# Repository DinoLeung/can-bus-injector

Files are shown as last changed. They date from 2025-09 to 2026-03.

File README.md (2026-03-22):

# CAN Pulse

## Overview

A simple ESP32-based device that listens to and forwards CAN bus data from the 2022+ Toyota GR86 / Subaru BRZ (ZN8/ZD8).
The goal is to make CAN bus data available in [RaceChrono](https://racechrono.com).
It taps into the ASC unit (the “GazooKazoo”), which reads CAN data to produce fake engine noise. Many owners leave it unplugged anyway, we repurpose the data stream from there.

## Motivation

RaceChrono supports [DIY BLE CAN devices](https://github.com/aollin/racechrono-ble-diy-device), which opens the door to building a fully custom telemetry pipeline. Instead of relying on off-the-shelf hardware, this project aims to create a lightweight, purpose-built device that integrates cleanly with the car and exposes exactly the data needed.

It’s also a practical exercise in understanding the vehicle’s CAN network and building something that is both functional and extensible, rather than a black box.

## Roadmap

### Current Status

The basic firmware is complete and functional:
- CAN frames are read from the vehicle bus.
- Data is cached and filtered.
- Frames are forwarded over BLE using the RaceChrono DIY device protocol.

This means the device is already usable for real-time telemetry in RaceChrono.

### Next Step: High-Rate GPS Integration

The next major milestone is adding high-frequency GPS data support using the [ASL GPS bolt-on](https://wiki.autosportlabs.com/Gps-bolt-on)

Planned capabilities:
- Integrate GPS data alongside CAN telemetry.
- Support higher update rates than typical phone-based GPS.
- Improve lap timing accuracy and track position fidelity.

Longer term, this will allow the device to act as a complete standalone telemetry unit, rather than relying on the phone for positioning data.

## Hardware

### [ASL ESP-CAN-X2](https://wiki.autosportlabs.com/ESP32-CAN-X2)
### [ASL Gps-bolt-on](https://wiki.autosportlabs.com/Gps-bolt-on)

## References

This project is heavily based on reverse engineering work documented by the community, in particular:
- https://github.com/timurrrr/ft86/blob/main/can_bus/gen2.md

That document provides a detailed breakdown of the Gen2 GR86/BRZ CAN bus signals and effectively serves as the foundation for this project. It guided the identification of useful frames, signal meanings, and overall approach to decoding and forwarding data.

Without that work, building a usable and accurate telemetry pipeline would be significantly more time-consuming.

## Oil Pressure Oil Temperature Bolt-on

### Status

Abandon for now or at least deprioritised, due to lack of PCB design skills.

<details>

<summary>details</summary>

### Motivation

The factory setup leaves much to be desired:
- The gauge cluster on BRZ lacks a proper, high-resolution oil temperature gauge.
- Oil pressure data is absent.

This project aims to fill that gap by:
- Forwarding CAN data from the ASC (Active Sound Control) unit to a new CAN output.
- Reading engine oil pressure using a Bosch analog fluid pressure sensor (0 to 10 bar).
- Reading engine oil temperature using a Bosch analog fluid temperature sensor (-40 to 150 °C).
- Injecting that data into the new CAN bus stream so that digital dashboards and logging tools (e.g. RaceChrono) can display it.

Accurate oil pressure monitoring is critical in performance and track environments — especially given the FA24 platform’s known vulnerability to oil starvation during high-G right-hand turns.

### Features

- Dual-CAN forwarding: Reads from CAN1 (TWAI), writes to CAN2 (MCP2515).
- Sensor integration: Adds real-time oil pressure and temperature data (40Hz sampling rate, 20Hz update rate).
- Plug-and-play install: Designed to interface cleanly with the ASC connector and ESP32.

### Hardware

#### [Custom ASL ESP32-CAN-X2 Bolt-on](./bolt-on-bosch-pst-f-1/)
#### [Bosch Pressure Sensor Combined PST-F 1](https://www.bosch-motorsport.com/content/downloads/Raceparts/en-GB/54249355.html)

</details>

## License

- **Firmware** (ESP32 code): [GPLv3](./LICENSE)
- **Hardware design** (schematics, PCB layout): [CERN-OHL-S v2](./bolt-on-bosch-pst-f-1/LICENSE)

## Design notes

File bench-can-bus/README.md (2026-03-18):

# Bench top can bus

This is to save me from getting actual can signal from the car while writing code. 

It's purely vibe coded, making [FakeSubaruBRZ.ino](https://github.com/timurrrr/arduino-CAN/blob/master/examples/FakeSubaruBRZ/FakeSubaruBRZ.ino) compatible with ESP32-CAN-X2, producing CAN data on CAN 1.

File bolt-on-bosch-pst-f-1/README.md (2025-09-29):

# PST-F1 Bolt-On Daughter Board for ESP32-CAN-X2

A small daughter-board that lets you easily attach a Bosch PST-F1 combined pressure + temperature sensor to the AutosportLabs ESP32-CAN-X2.

## Overview

This daughter-board provides ESP32-CAN-X2 an interface for the Bosch PST-F1 combined pressure and temperature sensor (0–10 bar pressure + NTC temperature). It uses a 4-pin JST connector for sensor inputs. The board also passes through CAN2 signals from the ESP32-CAN-X2.

## Features

- **PST-F1 support**: 4-pin input (5 V, PRESS_SIG, TEMP_SIG, GND)
- **Voltage scaling & protection** on both sensor outputs
- **0.1 µF decoupling** on analog rails
- **Pass-through** of CAN2 channel

## Hardware Requirements

- [AutosportLabs ESP32-CAN-X2](https://wiki.autosportlabs.com/ESP32-CAN-X2) board
- [Bosch PST-F1 combined pressure-temperature sensor](https://www.bosch-motorsport.com/content/downloads/Raceparts/en-GB/54249355.html)

## Pinout & Connections

| PST-F1 Pin | Signal | Daughter-Board Net | ESP32-CAN-X2 Pin |
|:---:|:---|:---|:---:|
| 1 | +5 V Supply  | 5V | SV1-pin 15 (5 V) |
| 2 | PRESS_SIG | PRESS_ADC | SV2-pin 13 (GPIO)|
| 3 | TEMP_SIG | TEMP_ADC | SV2-pin 12 (GPIO)|
| 4 | GND | GND | SV1-pin 16 (GND) |

## Analog Signal Scaling/Divider

### Pressure (0–10 bar → 0.32–2.88 V ADC)

- At 0.5 V (@ 0 bar / 0 PSI) -> ADC ≈ 0.32 V
- At 4.5 V (@ 10 bar / 145 PSI) -> ADC ≈ 2.88 V

``` mermaid
flowchart LR
  PSTF1_P["PST-F1 Pressure Out<br/>0.5 V @ 0 bar – 4.5 V @ 10 bar"]
  PRESS_ADC["PRESS_ADC Node"]
  R_SER_PRESS["R_SER_PRESS<br/>220 Ω"]
  R_PRESS_TOP["R_PRESS_TOP<br/>5.6 kΩ"]
  R_PRESS_BOT["R_PRESS_BOT<br/>10 kΩ"]
  D1["D1<br/>BAT54C"]
  D2["D2<br/>BAT54A"]
  C1["C1 Filter Cap<br/>0.1 µF"]
  GND["GND"]
  VCC["3.3 V"]
  GPIO["GPIO 35"]

  PSTF1_P --- R_SER_PRESS --- R_PRESS_TOP --- PRESS_ADC
  VCC ---|cathode| D1
  D1 ---|anode| PRESS_ADC
  GND ---|anode| D2
  D2 ---|cathode| PRESS_ADC
  PRESS_ADC --- R_PRESS_BOT --- GND
  PRESS_ADC --- C1 --- GND
  PRESS_ADC --- GPIO
```

### Temperature (NTC 58.1 Ω-44.864 kΩ → 0.01–2.9 V ADC)

- At cold (44 kΩ) → ADC ≈ 2.9 V
- At hot (58 Ω) → ADC ≈ 0.01 V

``` mermaid
flowchart LR
  PSTF1_P["PST-F1 Temperature Out<br/>44 kΩ @ –40 °C - 58 Ω @ +150 °C"]
  R_SER_TEMP["R_SER_TEMP<br/>220 Ω"]
  R_TEMP_TOP["R_TEMP_TOP<br/>6.8 kΩ"]
  TEMP_ADC["TEMP_ADC Node"]
  D1["D1<br/>BAT54C"]
  D2["D2<br/>BAT54A"]
  C2["C2 Filter Cap<br/>0.1 µF"]
  GND["GND"]
  VCC["3.3 V"]
  GPIO["GPIO 36"]

  PSTF1_P --- R_SER_TEMP --- TEMP_ADC
  TEMP_ADC --- C2 --- GND
  TEMP_ADC --- R_TEMP_TOP --- VCC
  VCC ---|cathode| D1  ---|anode| TEMP_ADC
  GND ---|anode| D2
  D2 ---|cathode| TEMP_ADC
  TEMP_ADC --- GPIO
```

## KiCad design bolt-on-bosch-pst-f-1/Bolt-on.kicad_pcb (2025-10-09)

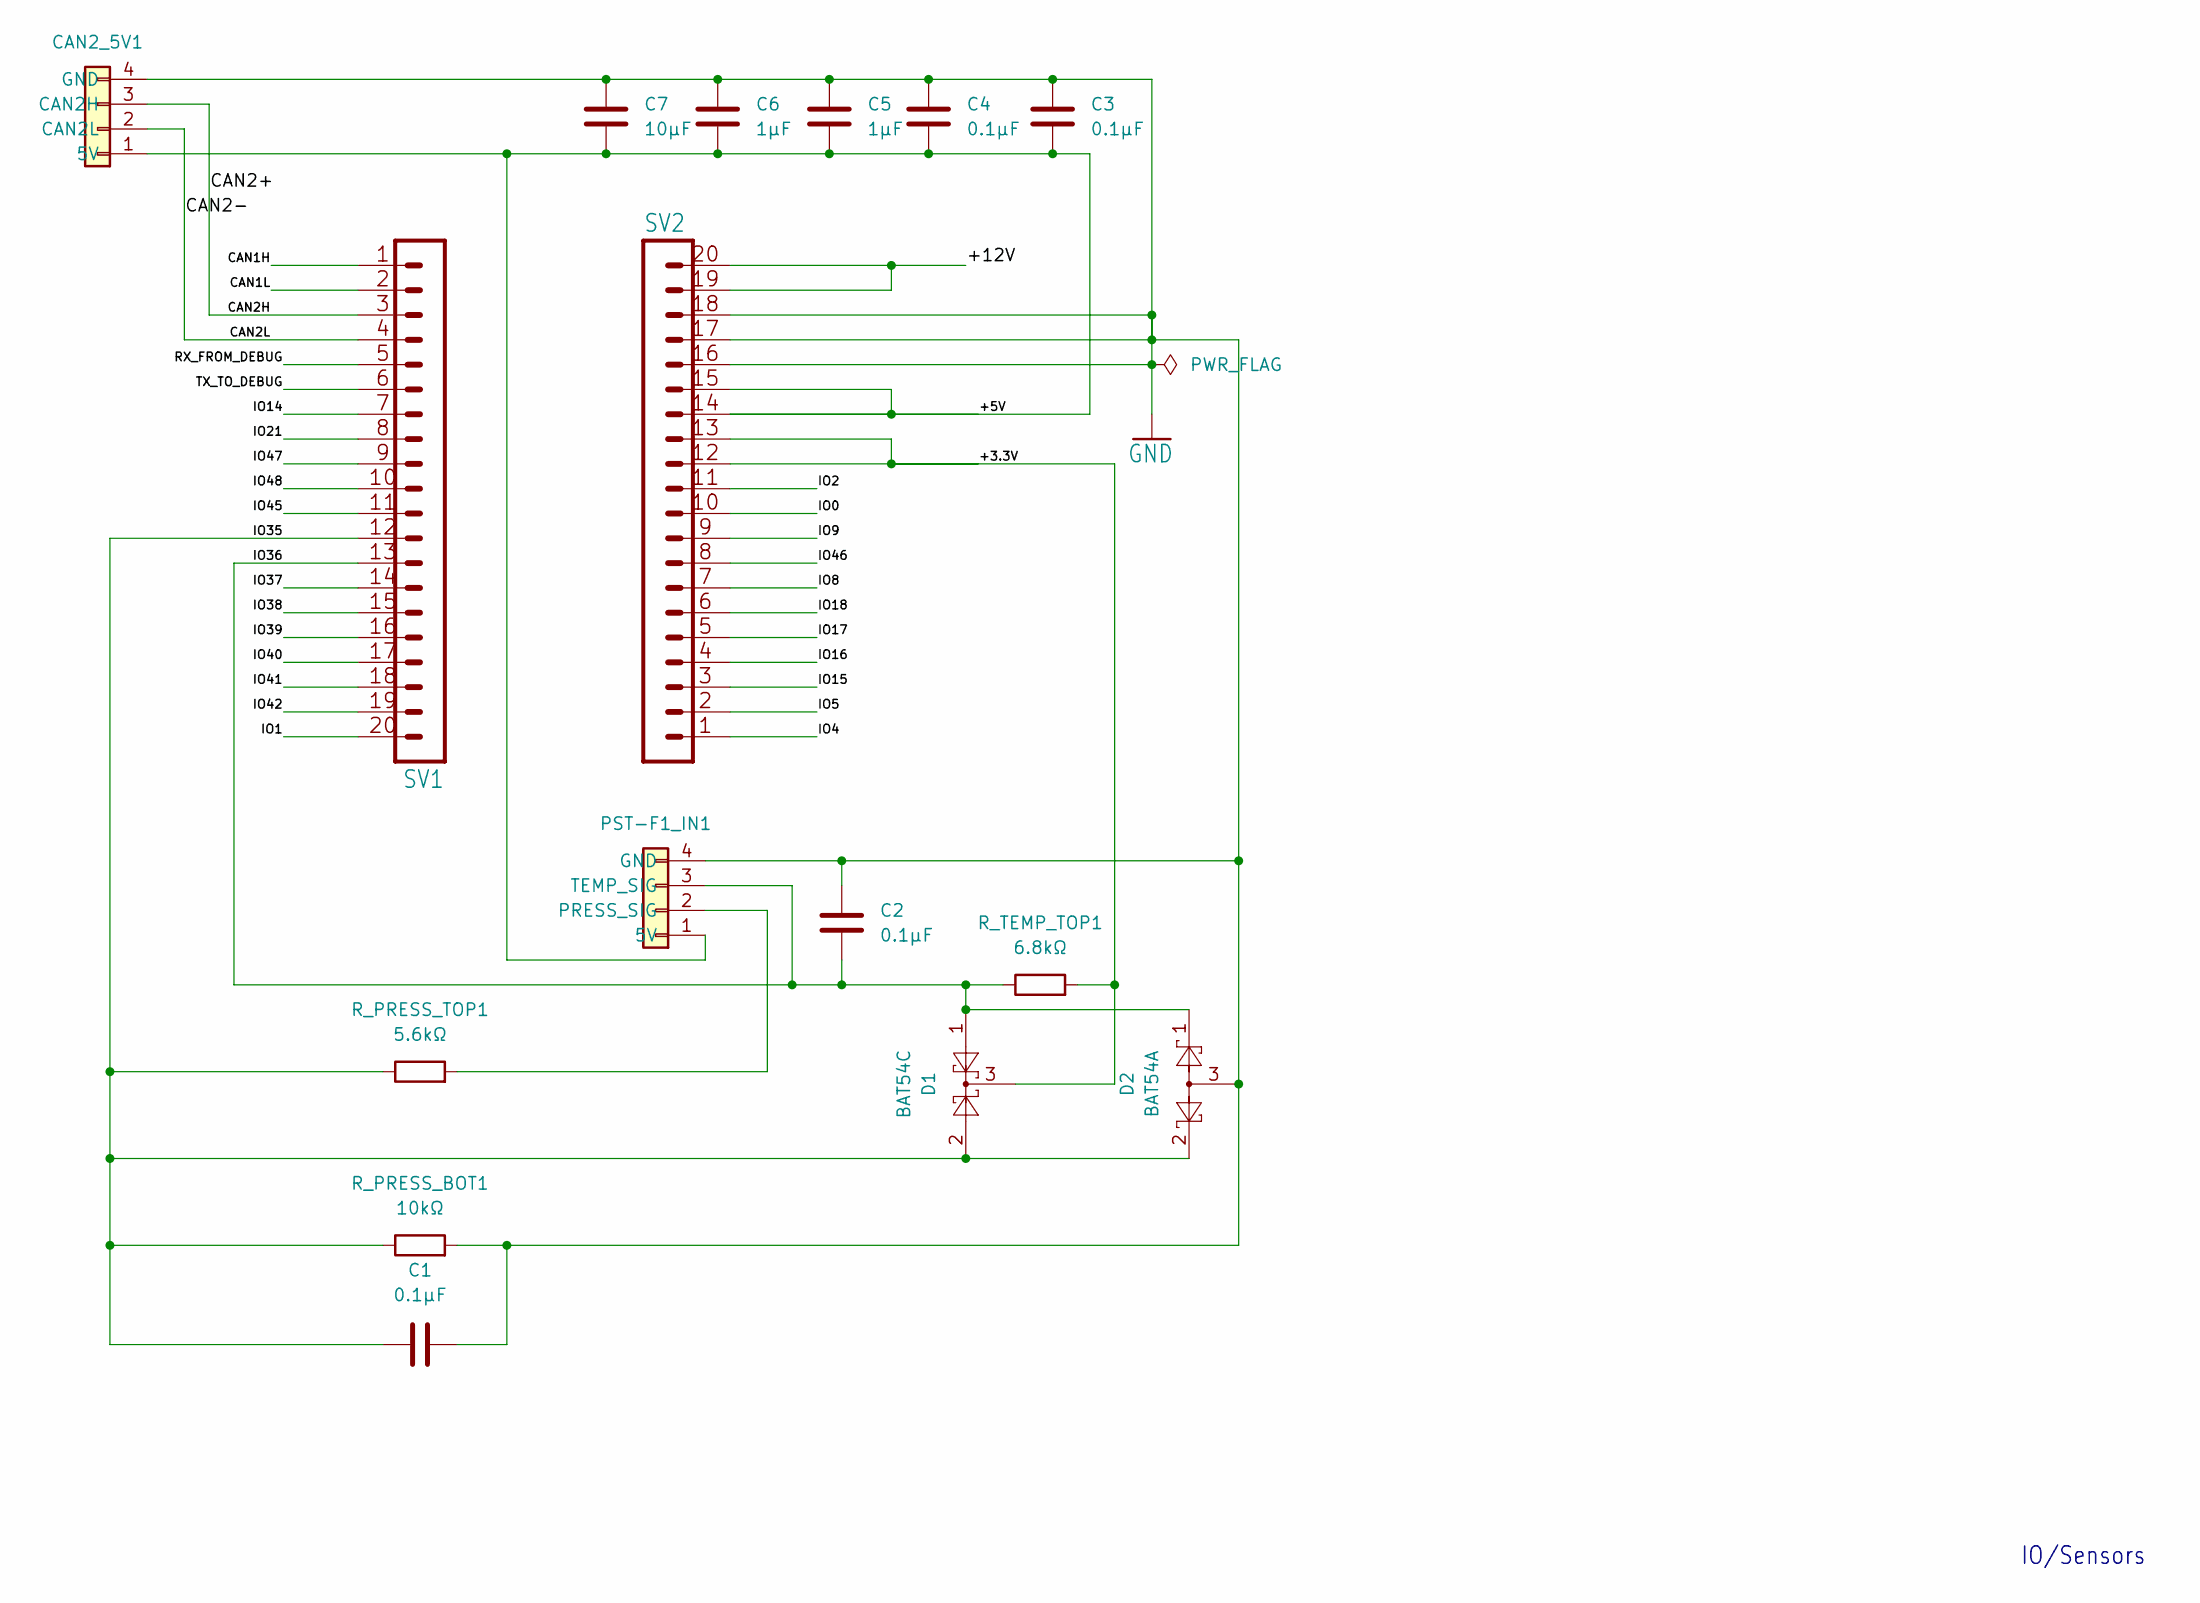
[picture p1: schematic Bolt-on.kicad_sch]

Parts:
C1, C2, C3, C4:  0.1µF; C_0805_2012Metric_Pad1.18x1.45mm_HandSolder
C5, C6: 1µF; C_0805_2012Metric_Pad1.18x1.45mm_HandSolder
C7: 10µF; C_1206_3216Metric_Pad1.33x1.80mm_HandSolder
CAN2_5V1: Conn_01x04; JST_PH_S4B-PH-SM4-TB_1x04-1MP_P2.00mm_Horizontal
D1: BAT54C; SOT-23_Handsoldering
D2: BAT54A; TSOT-23_HandSoldering
PST-F1_IN1: Conn_01x04; JST_PH_S4B-PH-SM4-TB_1x04-1MP_P2.00mm_Horizontal
R_PRESS_BOT1:  10kΩ; R_0805_2012Metric_Pad1.20x1.40mm_HandSolder
R_PRESS_TOP1:  5.6kΩ; R_0805_2012Metric_Pad1.20x1.40mm_HandSolder
R_TEMP_TOP1:  6.8kΩ; R_0805_2012Metric_Pad1.20x1.40mm_HandSolder
SV1, SV2: MA20-1L_162

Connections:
/+3.3V: D1.3, R_TEMP_TOP1.2, SV2.12, SV2.13
/+5V: C3.2, C4.2, C5.2, C6.2, C7.2, CAN2_5V1.1 (5V), PST-F1_IN1.1 (5V), SV2.14, SV2.15
/+12V: SV2.19, SV2.20
/CAN1H: SV1.1
/CAN1L: SV1.2
/CAN2+: CAN2_5V1.3 (CAN2H), SV1.3
/CAN2-: CAN2_5V1.2 (CAN2L), SV1.4
/IO0: SV2.10
/IO1: SV1.20
/IO2: SV2.11
/IO4: SV2.1
/IO5: SV2.2
/IO8: SV2.7
/IO9: SV2.9
/IO14: SV1.7
/IO15: SV2.3
/IO16: SV2.4
/IO17: SV2.5
/IO18: SV2.6
/IO21: SV1.8
/IO35: C1.2, D1.2, D2.2, R_PRESS_BOT1.1, R_PRESS_TOP1.1, SV1.12
/IO36: C2.2, D1.1, D2.1, PST-F1_IN1.3 (TEMP_SIG), R_TEMP_TOP1.1, SV1.13
/IO37: SV1.14
/IO38: SV1.15
/IO39: SV1.16
/IO40: SV1.17
/IO41: SV1.18
/IO42: SV1.19
/IO45: SV1.11
/IO46: SV2.8
/IO47: SV1.9
/IO48: SV1.10
/RX_FROM_DEBUG: SV1.5
/TX_TO_DEBUG: SV1.6
GND: C1.1, C2.1, C3.1, C4.1, C5.1, C6.1, C7.1, CAN2_5V1.4 (GND), D2.3, PST-F1_IN1.4 (GND), R_PRESS_BOT1.2, SV2.16, SV2.17, SV2.18
unnamed: PST-F1_IN1.2 (PRESS_SIG), R_PRESS_TOP1.2

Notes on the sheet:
IO/Sensors

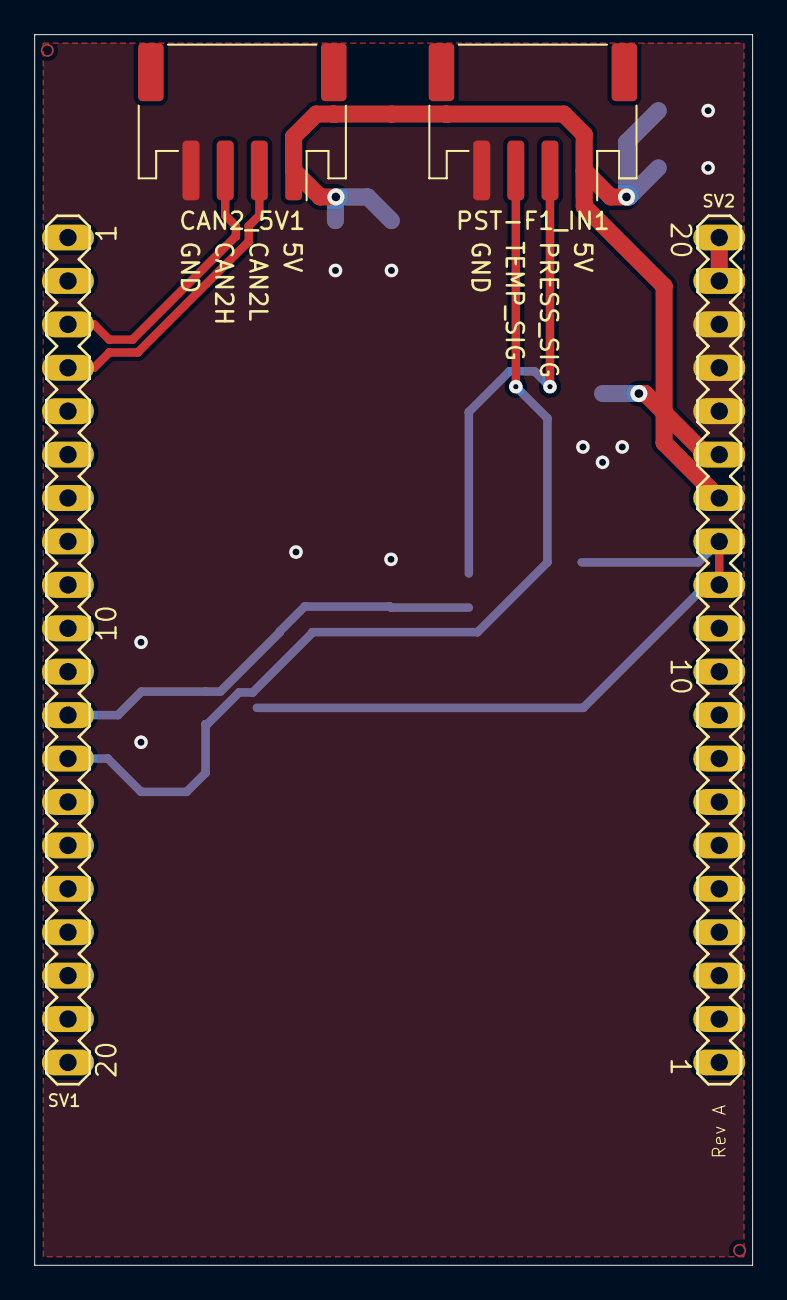
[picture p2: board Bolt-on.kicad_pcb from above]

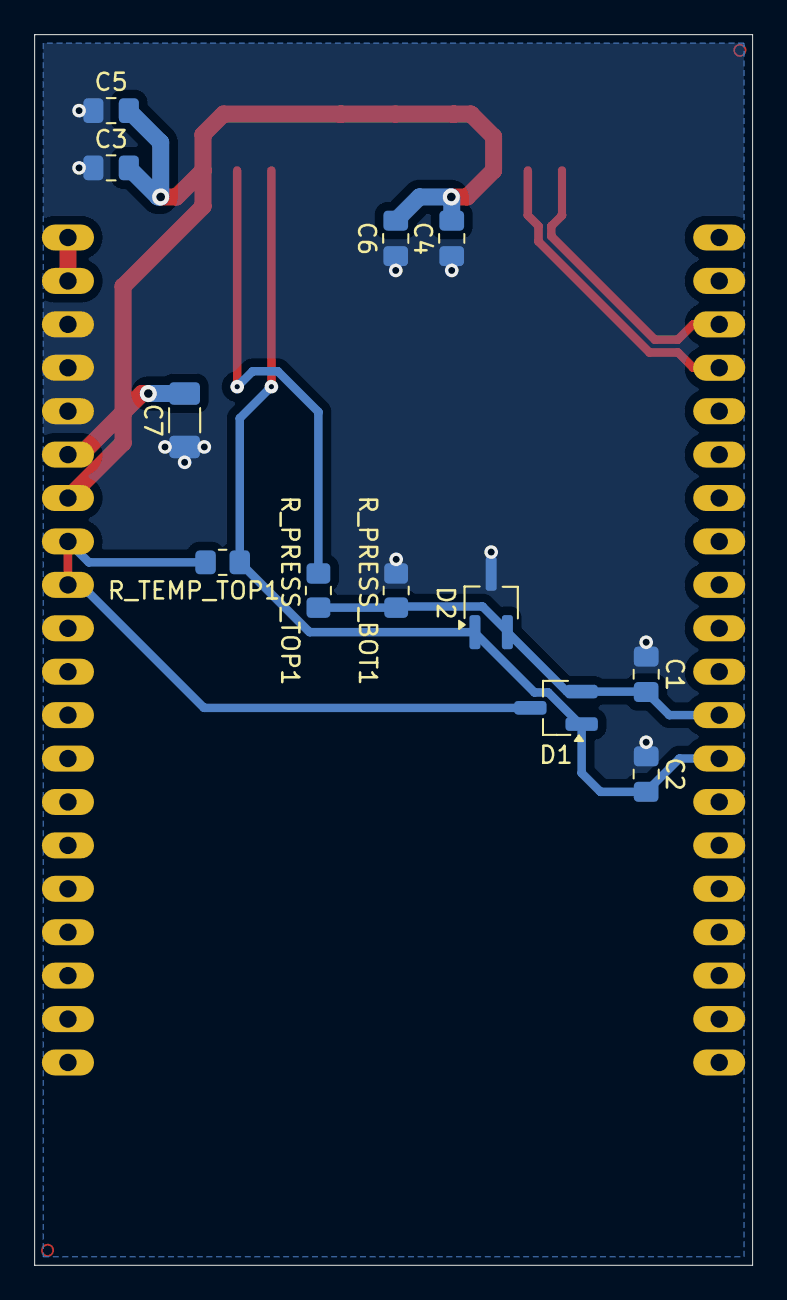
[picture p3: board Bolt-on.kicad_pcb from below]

Board: 2 copper layers, 42.0 x 72.0 mm, 16 parts (12 on the bottom side), 9 nets.

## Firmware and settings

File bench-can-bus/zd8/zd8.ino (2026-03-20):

#include <Arduino.h>
#include "driver/twai.h"

// BRZ bus speed from the original example
static constexpr uint32_t CAN_BITRATE = 500000;

// -------------------------------------------------------------------------------------------------
// Frame scheduler
// -------------------------------------------------------------------------------------------------

struct ScheduledPid {
  uint16_t pid;
  uint16_t rate_hz;
  uint32_t last_sent_us;
};

// Keep the same spirit as the original example:
// - 0x18, 0x140, 0x141, 0x142 at 100 Hz
// - several others at 50 / 20 / 10 / 16.7 Hz
ScheduledPid scheduledPids[] = {
  
  // somewhat real can data
  {0x040, 100, 0},
  {0x138,  50, 0},
  {0x139,  50, 0},
  {0x13B,  50, 0},
  {0x146,  50, 0},
  {0x241,  50, 0},
  {0x345,  50, 0},
  
  // placeholders
  {0x018, 100, 0},
  {0x390,  50, 0},
  {0x141, 100, 0},
  {0x142, 100, 0},
  {0x144,  50, 0},
  {0x152,  50, 0},
  {0x156,  50, 0},
  {0x280,  50, 0},
  {0x282,  17, 0},
  {0x284,  10, 0},

};

// -------------------------------------------------------------------------------------------------
// Helpers
// -------------------------------------------------------------------------------------------------

static inline uint16_t hzToPeriodUs(uint16_t hz) {
  return 1000000UL / hz;
}

bool sendFrame(uint16_t id, const uint8_t *payload, uint8_t len) {
  twai_message_t msg = {};
  msg.identifier = id;
  msg.extd = 0;
  msg.rtr = 0;
  msg.data_length_code = len;
  memcpy(msg.data, payload, len);

  esp_err_t err = twai_transmit(&msg, pdMS_TO_TICKS(50));
  if (err != ESP_OK) {
    Serial.printf("TX failed id=0x%03X err=%d\n", id, err);
    return false;
  }
  return true;
}

// -------------------------------------------------------------------------------------------------
// Fake BRZ payload generation
// -------------------------------------------------------------------------------------------------

void generatePayload(uint16_t pid, uint8_t *payload) {
  memset(payload, 0, 8);

  switch (pid) {
    case 0x018: {
      // Placeholder heartbeat frame.
      payload[0] = 0x00;
      payload[1] = 0x00;
      payload[2] = 0x00;
      payload[3] = 0x00;
      payload[4] = 0x00;
      payload[5] = 0x00;
      payload[6] = 0x00;
      payload[7] = 0x00;
      break;
    }

    case 0x040: {
      // engine speed / accelerator pos
      payload[0] = 0x00;
      payload[1] = 0x00;
      payload[2] = 0xCF;
      payload[3] = 0x82;
      payload[4] = 0x99;
      payload[5] = 0x00;
      payload[6] = 0x00;
      payload[7] = 0x00;
      break;
    }

    case 0x138: {
      // Steering / yaw
      payload[0] = 0x00;
      payload[1] = 0x00;
      payload[2] = 0xC1;
      payload[3] = 0xFF;
      payload[4] = 0xFA;
      payload[5] = 0x3F;
      payload[6] = 0x00;
      payload[7] = 0x00;
      break;
    }

    case 0x139: {
      // Speed / break pressure
      payload[0] = 0x00;
      payload[1] = 0x00;
      payload[2] = 0xFC;
      payload[3] = 0xE0;
      payload[4] = 0x00;
      payload[5] = 0x01;
      payload[6] = 0x00;
      payload[7] = 0x00;
      break;
    }

    case 0x13B: {
      // acceleration
      payload[0] = 0x00;
      payload[1] = 0x00;
      payload[2] = 0x00;
      payload[3] = 0x00;
      payload[4] = 0x00;
      payload[5] = 0x0;
      payload[6] = 0xFE;
      payload[7] = 0xFD;
      break;
    }

    case 0x146: {
      // acceleration
      payload[0] = 0x00;
      payload[1] = 0x00;
      payload[2] = 0x00;
      payload[3] = 0x00;
      payload[4] = 0x89;
      payload[5] = 0x00;
      payload[6] = 0x00;
      payload[7] = 0x00;
      break;
    }

    case 0x241: {
      // acceleration
      payload[0] = 0x00;
      payload[1] = 0x00;
      payload[2] = 0x00;
      payload[3] = 0x00;
      payload[4] = 0x30;
      payload[5] = 0x00;
      payload[6] = 0x00;
      payload[7] = 0x00;
      break;
    }

    case 0x345: {
      // acceleration
      payload[0] = 0x00;
      payload[1] = 0x00;
      payload[2] = 0x00;
      payload[3] = 0x84;
      payload[4] = 0x82;
      payload[5] = 0x12;
      payload[6] = 0x00;
      payload[7] = 0x00;
      break;
    }
    
    case 0x390: {
      // acceleration
      payload[0] = 0x00;
      payload[1] = 0x00;
      payload[2] = 0x00;
      payload[3] = 0x00;
      payload[4] = 0x90;
      payload[5] = 0x00;
      payload[6] = 0x00;
      payload[7] = 0x00;
      break;
    }

    case 0x0D2: {
      // Placeholder
      payload[0] = 0x11;
      payload[1] = 0x22;
      payload[2] = 0x33;
      payload[3] = 0x44;
      break;
    }

    case 0x0D3: {
      // Placeholder
      payload[0] = 0x55;
      payload[1] = 0x66;
      payload[2] = 0x77;
      payload[3] = 0x88;
      break;
    }

    case 0x141: {
      // Placeholder
      payload[0] = 0x01;
      payload[1] = 0x02;
      payload[2] = 0x03;
      payload[3] = 0x04;
      break;
    }

    case 0x142: {
      // Placeholder
      payload[0] = 0x10;
      payload[1] = 0x20;
      payload[2] = 0x30;
      payload[3] = 0x40;
      break;
    }

    case 0x144: {
      // Placeholder
      payload[0] = 0xAA;
      payload[1] = 0xBB;
      payload[2] = 0xCC;
      payload[3] = 0xDD;
      break;
    }

    case 0x152: {
      // Placeholder
      payload[0] = 0x12;
      payload[1] = 0x34;
      payload[2] = 0x56;
      payload[3] = 0x78;
      break;
    }

    case 0x156: {
      // Placeholder
      payload[0] = 0x9A;
      payload[1] = 0xBC;
      payload[2] = 0xDE;
      payload[3] = 0xF0;
      break;
    }

    case 0x280: {
      // Placeholder
      payload[0] = 0x01;
      break;
    }

    case 0x282: {
      // Placeholder
      payload[0] = 0x02;
      break;
    }

    case 0x284: {
      // Placeholder
      payload[0] = 0x03;
      break;
    }

    default:
      break;
  }
}

// -------------------------------------------------------------------------------------------------
// Setup / loop
// -------------------------------------------------------------------------------------------------

void setup() {
  Serial.begin(115200);
  delay(300);

  Serial.println("Initializing CAN1 (TWAI) on ESP32-CAN-X2...");

  twai_general_config_t g_config =
    TWAI_GENERAL_CONFIG_DEFAULT((gpio_num_t)CAN1_TX, (gpio_num_t)CAN1_RX, TWAI_MODE_NO_ACK);
  twai_timing_config_t t_config = TWAI_TIMING_CONFIG_500KBITS();
  twai_filter_config_t f_config = TWAI_FILTER_CONFIG_ACCEPT_ALL();

  esp_err_t err = twai_driver_install(&g_config, &t_config, &f_config);
  if (err != ESP_OK) {
    Serial.printf("twai_driver_install failed: %d\n", err);
    while (true) delay(1000);
  }

  err = twai_start();
  if (err != ESP_OK) {
    Serial.printf("twai_start failed: %d\n", err);
    while (true) delay(1000);
  }

  Serial.println("CAN1 started at 500 kbit/s");
}

void loop() {
  uint32_t nowUs = micros();

  for (size_t i = 0; i < sizeof(scheduledPids) / sizeof(scheduledPids[0]); i++) {
    ScheduledPid &entry = scheduledPids[i];
    const uint32_t periodUs = hzToPeriodUs(entry.rate_hz);

    if ((uint32_t)(nowUs - entry.last_sent_us) >= periodUs) {
      uint8_t payload[8];
      generatePayload(entry.pid, payload);

      if (sendFrame(entry.pid, payload, 8)) {
        entry.last_sent_us = nowUs;
      } else {
        // Don't spam this too hard on a busy bus
        Serial.printf("TX failed for 0x%03X\n", entry.pid);
      }
    }
  }

  // Keep loop tight but not stupidly busy
  delayMicroseconds(200);
}

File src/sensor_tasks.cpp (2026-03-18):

#include "sensor_tasks.h"
#include <Arduino.h>
#include <cmath>
#include "sensor_readings.h"
#include "sensor_math.h"
#include "can_bus.h"

// PST-F1 signal pins
#define PRESSURE_PIN GPIO_NUM_35
#define TEMPERATURE_PIN GPIO_NUM_36

// Custom CAN ID
#define CAN_ID 0x7e0

// 40Hz
constexpr TickType_t sensorSampleInterval = pdMS_TO_TICKS(25);
// 20Hz
constexpr TickType_t sensorCanMsgInterval = pdMS_TO_TICKS(50);

void pressureSamplingTask(void*);
void temperatureSamplingTask(void*);
static void sensorCanWriterTask(void*);

void startSensorTasks() {
	// Configure ADC resolution and attenuation for analog sensors
	analogReadResolution(12);
	analogSetPinAttenuation(PRESSURE_PIN, ADC_11db);
	analogSetPinAttenuation(TEMPERATURE_PIN, ADC_11db);

	xTaskCreate(pressureSamplingTask, "Oil_Pres", 2048, NULL, 1, NULL);
	xTaskCreate(temperatureSamplingTask, "Oil_Temp", 2048, NULL, 1, NULL);
	xTaskCreate(sensorCanWriterTask, "Sensor_CAN_Writer", 2048, NULL, 1, NULL);
}

/**
 * @brief FreeRTOS task that samples and processes oil pressure sensor readings.
 *
 * This task runs at 40 Hz. It reads the analog voltage from the oil pressure sensor,
 * converts it to voltage using adcToVoltage(), then computes pressure in psi via computePressurePsi().
 * The computed value is scaled to 0.1 psi resolution and stored in g_oilPressurePsi10.
 * If the ADC voltage is invalid, g_oilPressurePsi10 is set to INT16_MAX.
 *
 * @param pvParameters Unused.
 */
void pressureSamplingTask(void* pvParameters) {
	(void)pvParameters;
	TickType_t lastWake = xTaskGetTickCount();
	while (true) {
		int raw = analogRead(PRESSURE_PIN);
		float vAdc = adcToVoltage(raw);
		float pressurePsi = computePressurePsi(vAdc);

		if (isnan(pressurePsi)) {
			g_oilPressurePsi10 = INT16_MAX;
		} else {
			g_oilPressurePsi10 = static_cast<uint16_t>(pressurePsi * 10.0f);
		}

		vTaskDelayUntil(&lastWake, sensorSampleInterval);
	}
}

/**
 * @brief FreeRTOS task that samples and processes oil temperature sensor readings.
 *
 * This task runs at 40 Hz. It reads the analog voltage from the NTC temperature sensor,
 * converts it to voltage using adcToVoltage(), then computes temperature in Celsius
 * via computeTemperatureC(). The computed value is scaled to 0.1 °C resolution and stored in g_oilTempC10.
 * If the ADC voltage is invalid, g_oilTempC10 is set to INT16_MAX.
 *
 * @param pvParameters Unused.
 */
void temperatureSamplingTask(void* pvParameters) {
	(void)pvParameters;
	TickType_t lastWake = xTaskGetTickCount();
	while (true) {
		int raw = analogRead(TEMPERATURE_PIN);
		float vAdc = adcToVoltage(raw);
		float tempC = computeTemperatureC(vAdc);

		if (isnan(tempC)) {
			g_oilTempC10 = INT16_MAX;
		} else {
			g_oilTempC10 = static_cast<int16_t>(tempC * 10.0f);
		}

		vTaskDelayUntil(&lastWake, sensorSampleInterval);
	}
}

/**
 * @brief FreeRTOS task that periodically sends combined sensor values to CAN2.
 *
 * This task constructs a 4-byte CAN frame every 50 ms (20 Hz) that includes:
 * - Bytes 0–1: Oil pressure in deci-psi (uint16_t)
 * - Bytes 2–3: Oil temperature in deci-degrees Celsius (int16_t, two's complement)
 *
 * The values are read from shared volatile variables `g_oilPressurePsi10` and `g_oilTempC10`,
 * and sent as a standard 11-bit CAN frame using the identifier defined by `CAN_ID`.
 *
 * @param pvParameters Unused parameter for FreeRTOS compatibility.
 */
void sensorCanWriterTask(void* pvParameters) {
	(void)pvParameters;
	TickType_t lastWake = xTaskGetTickCount();
	while (true) {
		twai_message_t msg{};
		// Pack signed temperature (deci-°C) as two's‑complement uint16_t
		uint16_t rawTemp = static_cast<uint16_t>(g_oilTempC10);
		msg.identifier = CAN_ID;
		msg.extd = 0;
		msg.data_length_code = 4;
		msg.data[0] = uint8_t(g_oilPressurePsi10 >> 8);
		msg.data[1] = uint8_t(g_oilPressurePsi10 & 0xFF);
		msg.data[2] = uint8_t(rawTemp >> 8);
		msg.data[3] = uint8_t(rawTemp & 0xFF);
		writeCan2(msg);
		vTaskDelayUntil(&lastWake, sensorCanMsgInterval);
	}
}

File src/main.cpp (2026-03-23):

#include <Arduino.h>
#include "can_bus.h"
#include "can_frame_cache.h"
#include "gps.h"
#include "rc_ble.h"
#include "sensor_tasks.h"
#include "can_tasks.h"
#include "gps_tasks.h"
#include "rc_ble_tasks.h"

void setup() {
	initCanFrameCache();

	initCanBus();
	// initGps();
	initRaceChronoBle();
	
	startCanTasks();
	// startGpsTasks();
	// startSensorTasks();
	startRaceChronoTasks();
}

void loop() { /* DO NOTHING */ }

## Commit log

2025-07-18 designing circuit board for bosch sensor
    [Bolt-On Template.brd, Bolt-On Template.sch]
2025-07-25 designed circuit board for bosch sensor
    [Bolt-On Template.brd, Bolt-On Template.sch]
2025-07-25 added labels to circuit board
    [Bolt-On Template.brd]
2025-07-26 added readme for daughter board design
    [Bolt-On Template.brd, Bolt-On Template.sch]
2025-07-26 cleanup board design
    [Bolt-On Template.brd, Bolt-On Template.sch]
2025-07-27 implement basic can bus forwarder logic
2025-07-27 fix can1ReadTask param typo
    [main.cpp]
2025-07-27 implemented sensor sample logic, and custom can writer logic
2025-07-28 update temperature to signed int, update data sample tasks to 40hz
2025-07-29 add labels to jst pins
    [Bolt-On Template.brd, Bolt-On Template.sch]
2025-07-30 implement Steinhart–Hart equation for temps sensor
2025-08-03 redo pcb in kicad
    [Bolt-On Template.brd, Bolt-On Template.sch, Bolt-on.kicad_pcb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]
2025-08-03 updated temperature sensor sampling task
2025-08-03 cleanup kicad design
    [Bolt-on.kicad_pcb, Bolt-on.kicad_sch]
2025-08-03 fixed resistors name
    [Bolt-on.kicad_sch]
2025-08-06 add copper pour to gnd and 5v
    [Bolt-on.kicad_pcb, Bolt-on.kicad_sch]
2025-08-06 swaped jst positions
    [Bolt-on.kicad_pcb, Bolt-on.kicad_sch]
2025-08-07 move python math script to sensor_math lib
2025-08-09 redo board layout
    [Bolt-on.kicad_pcb]
2025-08-10 update board layout
    [Bolt-on.kicad_pcb, Bolt-on.kicad_sch]
2025-08-10 added low diode for proper clamp
    [Bolt-on.kicad_pcb, Bolt-on.kicad_sch]
2025-09-29 pcb add ground copper pour on both sides
    [Bolt-on.kicad_pcb, Bolt-on.kicad_sch]
2025-10-09 pcb added tented gnd vias
    [Bolt-on.kicad_pcb, Bolt-on.kicad_sch]
2026-03-18 cache can frames received
2026-03-18 cleanup can frame cache
2026-03-19 implemented logic to take racechrono pid filter commands
2026-03-19 implemented allow all logic, implementing specific pid list
2026-03-20 reset filter request to deny all on disconnect
    [rc_ble.cpp, rc_ble_tasks.cpp]
2026-03-20 updated bench can device frames
2026-03-20 cleaup bench can device code

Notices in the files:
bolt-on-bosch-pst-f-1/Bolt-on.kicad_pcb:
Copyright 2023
